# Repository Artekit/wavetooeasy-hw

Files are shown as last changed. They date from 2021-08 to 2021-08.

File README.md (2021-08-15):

# Artekit WaveTooEasy - Hardware files

This repository contains the Eagle files and mechanical drawings for the [Artekit WaveTooEasy](https://www.artekit.eu/products/devboards/wavetooeasy/) board.

(https://www.artekit.eu/products/devboards/wavetooeasy/)

## Links

* [WaveTooEasy product page](https://www.artekit.eu/products/devboards/wavetooeasy/)
* [WaveTooEasy manual](https://www.artekit.eu/doc/guides/wavetooeasy/)
* [WaveTooEasy - Library for Arduino](https://github.com/Artekit/Artekit_WaveTooEasy)
* [WaveTooEasy - Generic C library](https://github.com/Artekit/wavetooeasy-c-lib)

## Bugs report

You can report bugs here by creating a new issue or in the [Artekit forum](https://forum.artekit.eu/).

## License

Attribution-ShareAlike 3.0 Unported (CC BY-SA 3.0)

Copyright (c) 2021 Artekit Labs.

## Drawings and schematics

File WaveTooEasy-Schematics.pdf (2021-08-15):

# MCU ARM CORTEX M4 MECHANICAL

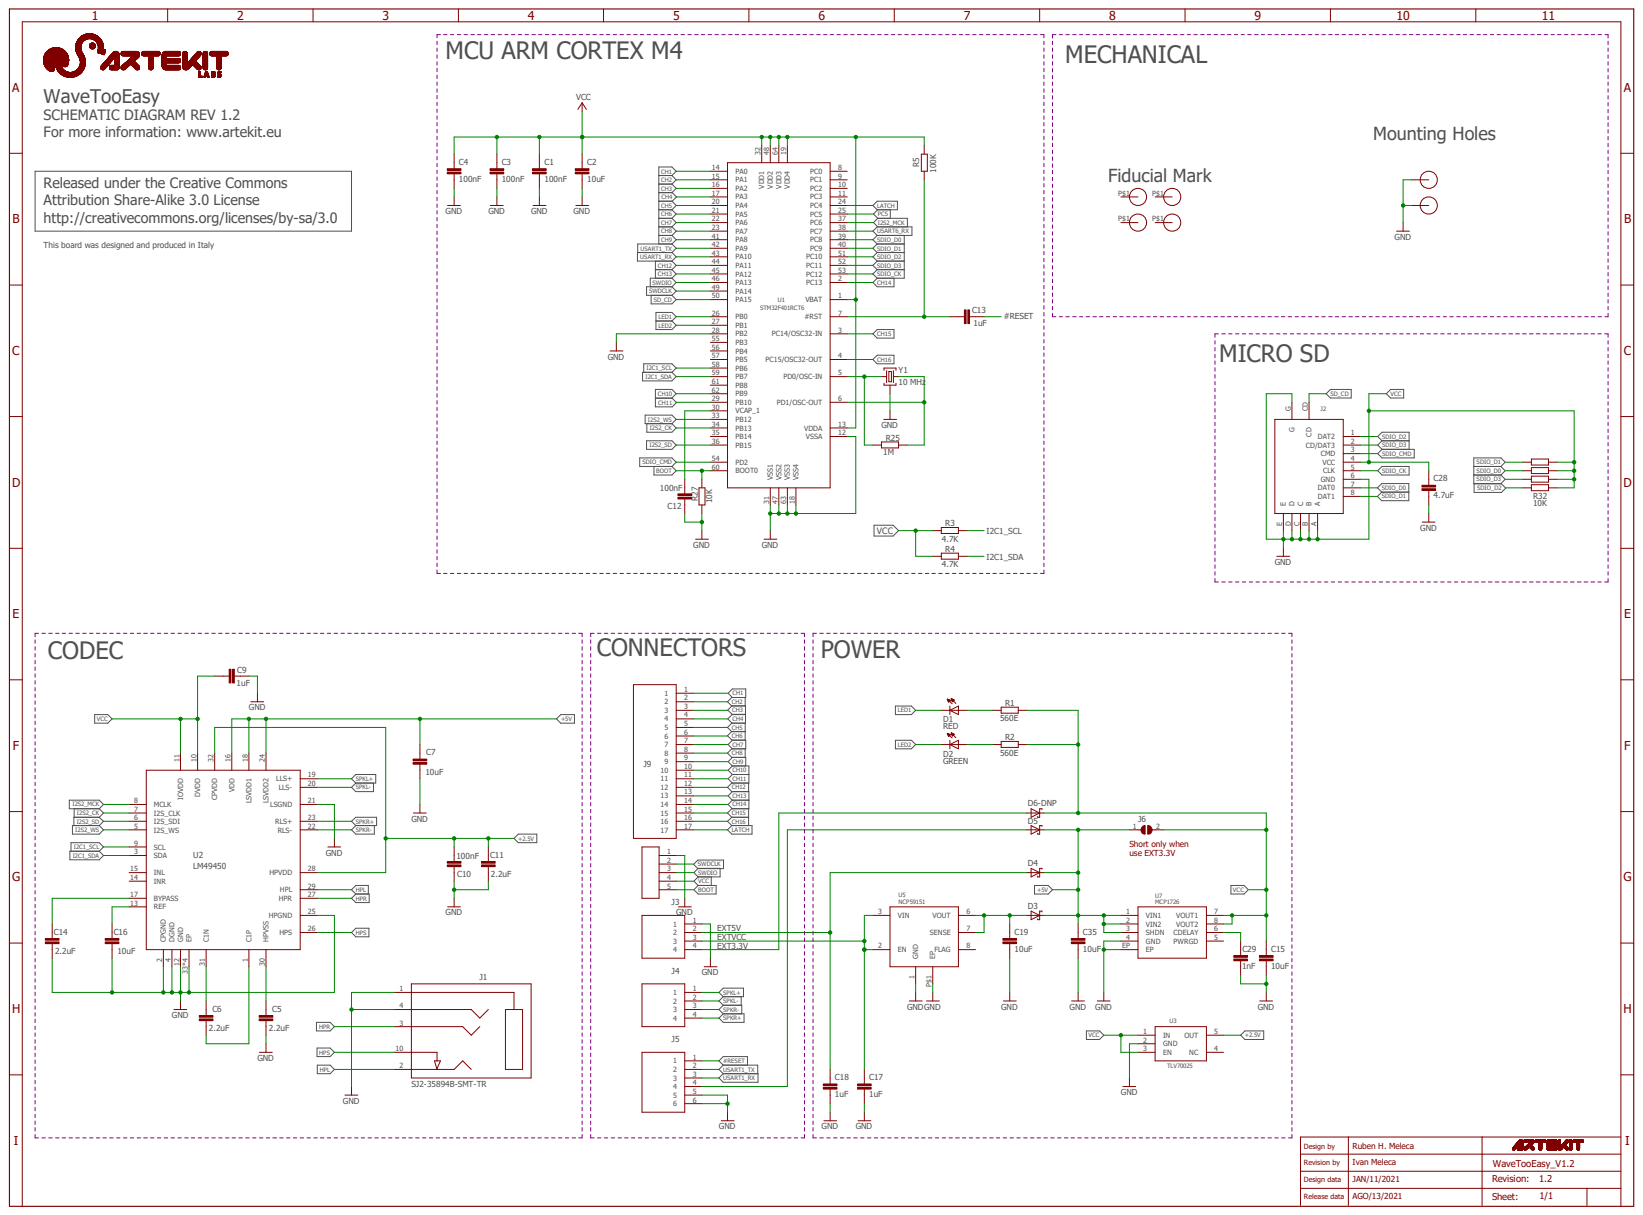
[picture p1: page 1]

WaveTooEasy
SCHEMATIC DIAGRAM REV 1.2
For more information: www.artekit.eu

Released under the Creative Commons
Attribution Share-Alike 3.0 License
http://creativecommons.org/licenses/by-sa/3.0

3 | EXTVCC

Design by | Ruben H. Meleca
Revision by | Ivan Meleca | WaveTooEasy_V1.2

Design data | JAN/11/2021 | Revision: 1.2
Release data | AGO/13/2021 | Sheet: 1/1

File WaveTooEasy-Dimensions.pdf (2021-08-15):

1.90 4.50 14.16

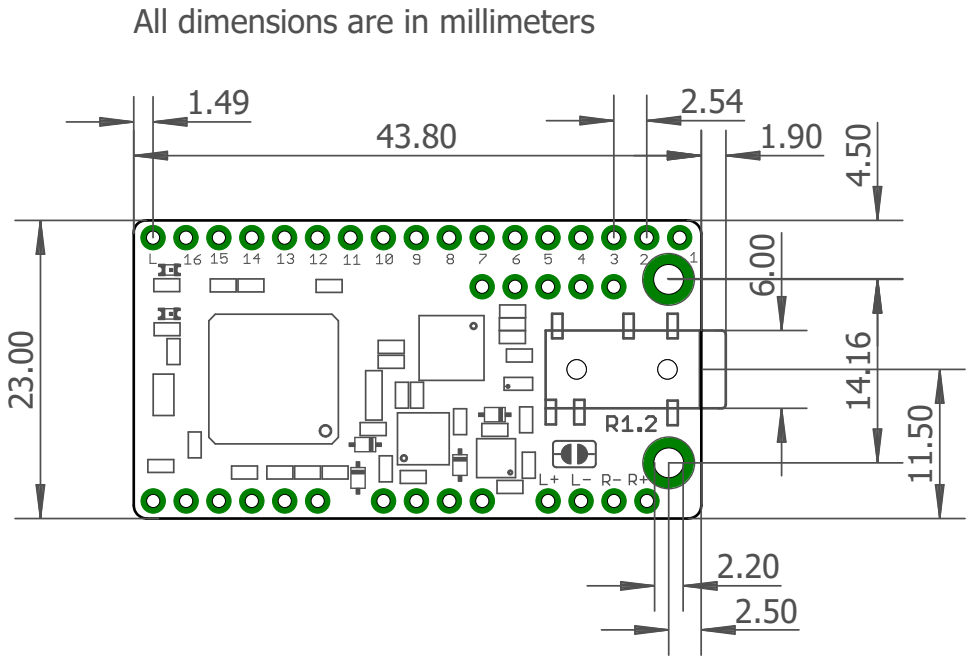
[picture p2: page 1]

All dimensions are in millimeters

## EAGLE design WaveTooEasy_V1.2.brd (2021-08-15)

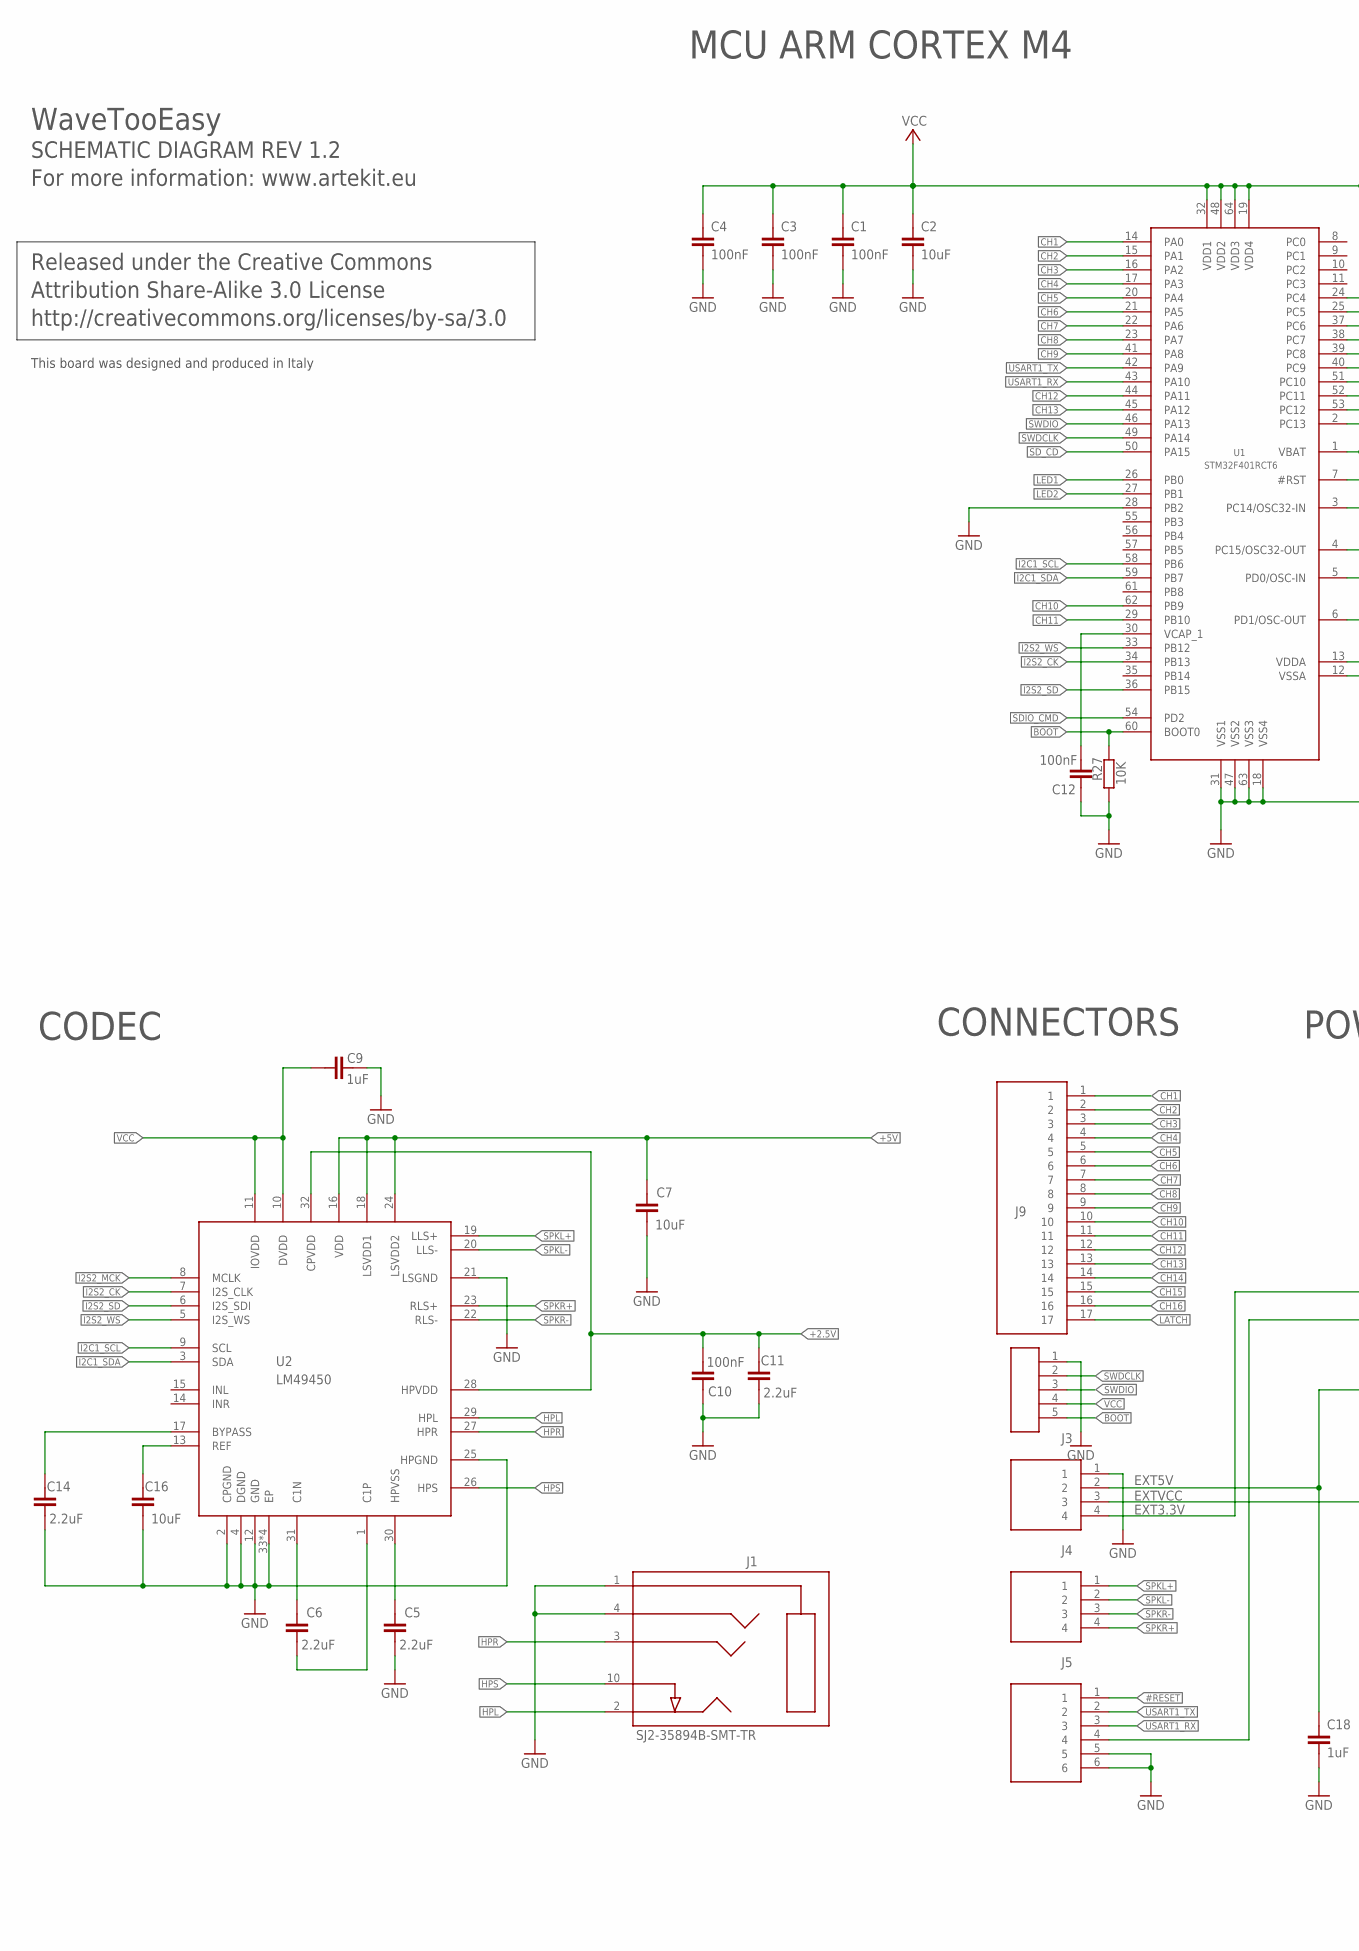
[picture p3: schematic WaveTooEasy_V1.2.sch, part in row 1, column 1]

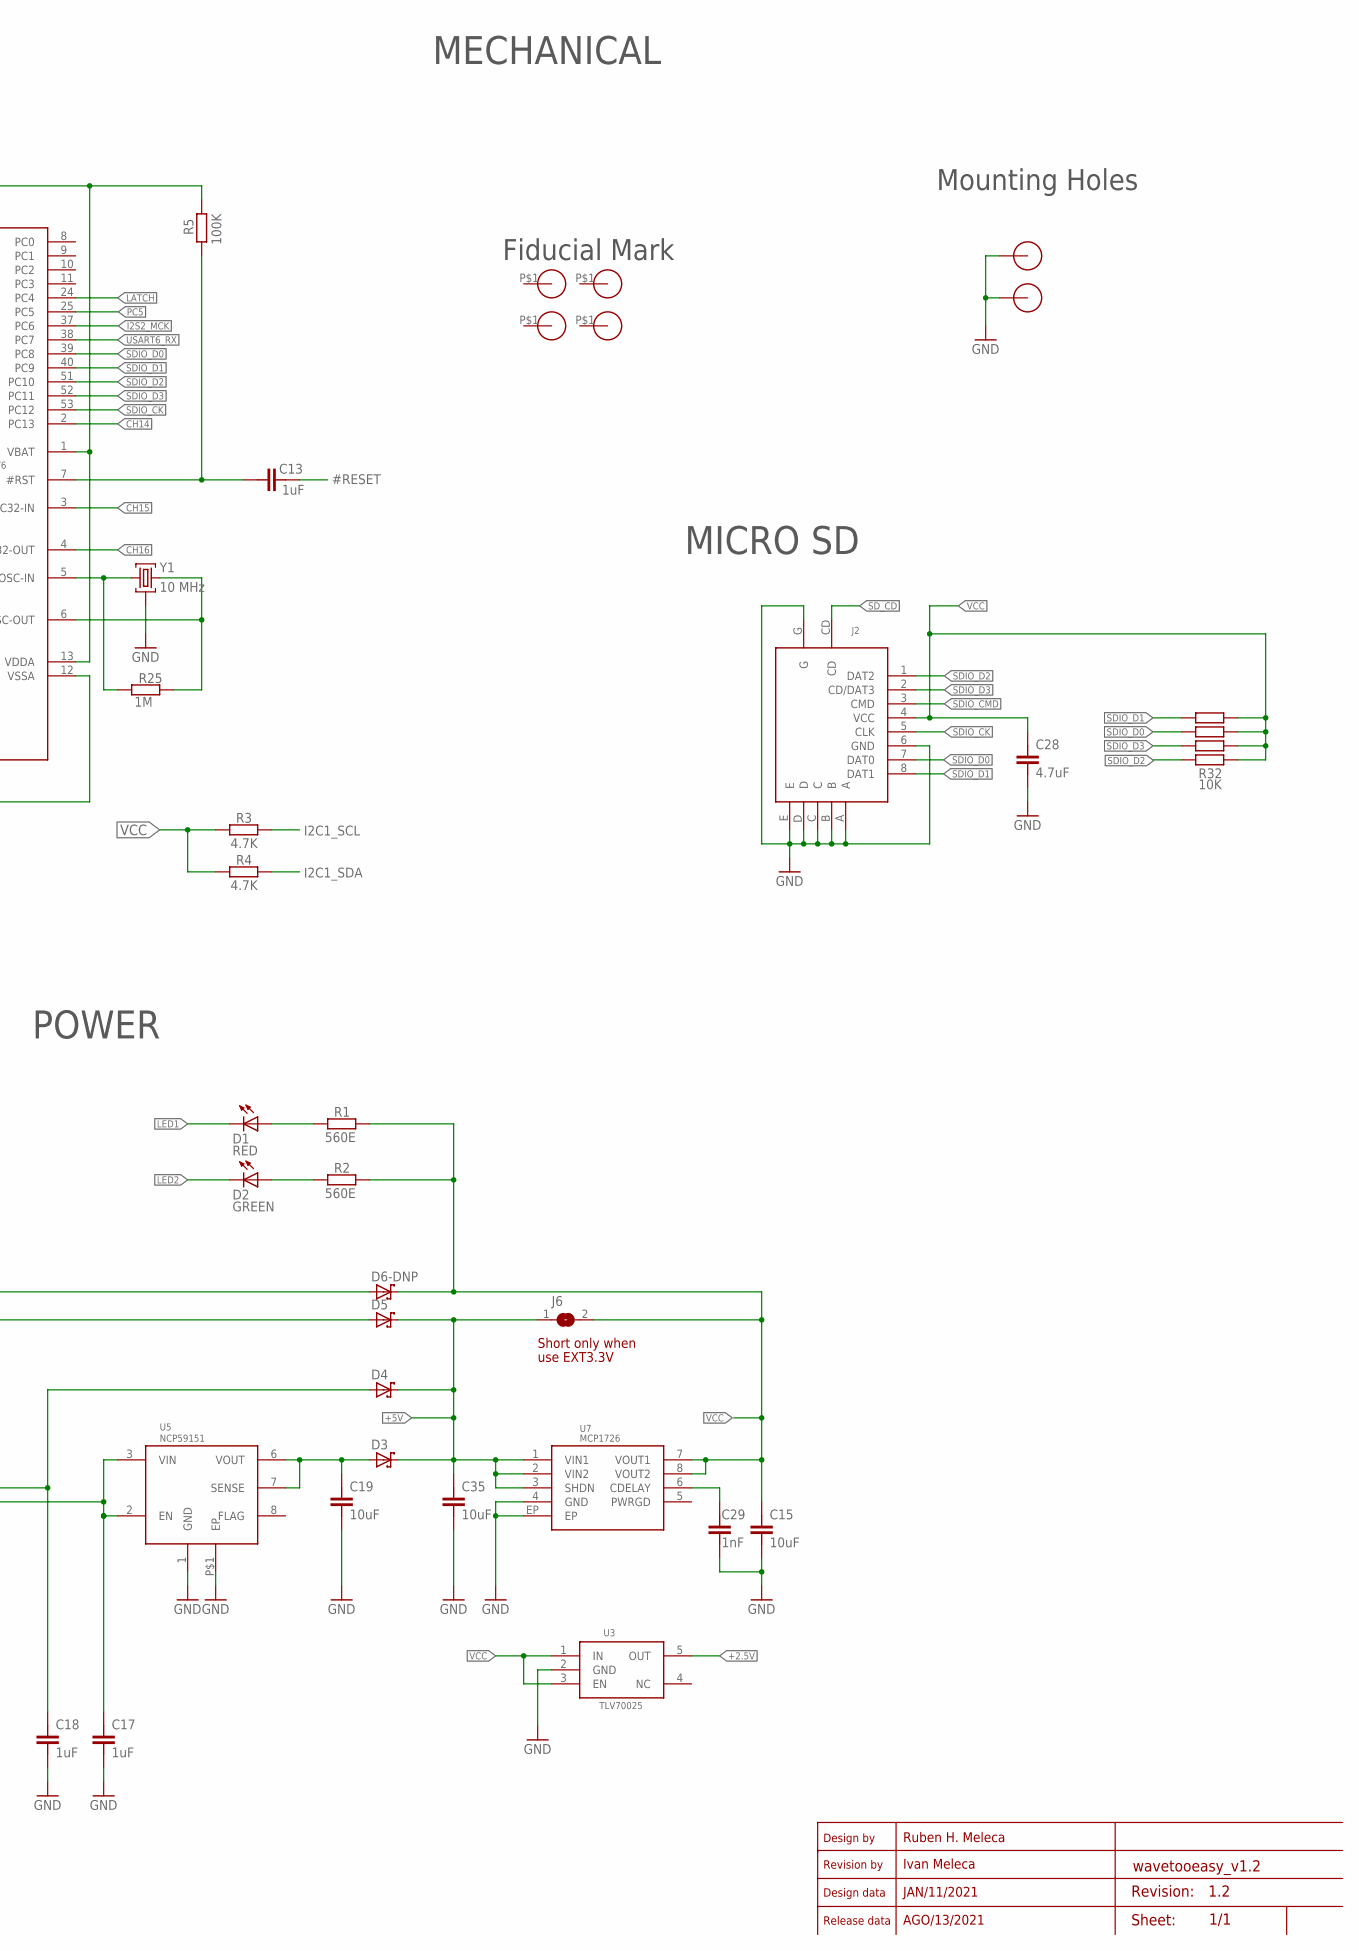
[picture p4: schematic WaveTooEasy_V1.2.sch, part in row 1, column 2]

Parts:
C1, C3, C4, C10, C12: 100nF; C0402
C2, C7, C15, C16, C19, C35: 10uF; C0402
C5, C6, C11, C14: 2.2uF; C0402
C9, C13, C17, C18: 1uF; C0402
C28: 4.7uF; C0402
C29: 1nF; C0402
D1: RED; CHIPLED_0603
D2: GREEN; CHIPLED_0603
D3, D4, D5, D6-DNP: BAT60; SOD-323
J1: SJ2-35894B-SMT-TR
J2: MICRO-SD-CON-MOLEX-503182-0852
J3, J4: CON-PH-1X04-P01"2; PIN-HEADER-1X04-NODASH
J5: CON-PH-1X06-P0.1"1; PIN-HEADER-1X6-NODASH
J6: JUMPER-2
J9: CON-PH-1X17-P0.1; PIN-HEADER-1X17-NODASH
R1, R2: 560E; R0402
R3, R4: 4.7K; R0402
R5: 100K; R0402
R25: 1M; R0402
R27: 10K; R0402
R32: 10K; RES-ARRAY-0603
U1: STM32F401RCT6; LQFP64-10X10-P0.50; MPN STM32F401RCT6
U2: LM49450; QFN32-5X5-P0.50
U3: TLV70025; SOT363-5
U5: NCP59151; DFN8-4X4
U7: MCP1726; DFN8-3X3
U$1: CON-PH-1X05-P0.1"; PIN-HEADER-1X05-NODASH
U$3, U$4: HOLE-2MM-METALIZED
U$5, U$6, U$8, U$9: FIDUTIAL_1.2MM
Y1: 10 MHz; RESONATOR-MURATA-CSTCE-SERIES

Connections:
#RESET: C13.2, J5.1
+2.5V: C10.1, C11.1, U2.28 (HPVDD), U2.32 (CPVDD), U3.5 (OUT)
+5V: C7.1, C35.1, D3.C, D4.C, D5.C, J6.1, U2.16 (VDD), U2.18 (LSVDD1), U2.24 (LSVDD2), U7.1 (VIN1), U7.2 (VIN2), U7.3 (SHDN)
BOOT: R27.2, U1.60 (BOOT0), U$1.5
CH1: J9.1, U1.14 (PA0)
CH2: J9.2, U1.15 (PA1)
CH3: J9.3, U1.16 (PA2)
CH4: J9.4, U1.17 (PA3)
CH5: J9.5, U1.20 (PA4)
CH6: J9.6, U1.21 (PA5)
CH7: J9.7, U1.22 (PA6)
CH8: J9.8, U1.23 (PA7)
CH9: J9.9, U1.41 (PA8)
CH10: J9.10, U1.62 (PB9)
CH11: J9.11, U1.29 (PB10)
CH12: J9.12, U1.44 (PA11)
CH13: J9.13, U1.45 (PA12)
CH14: J9.14, U1.2 (PC13)
CH15: J9.15, U1.3 (PC14/OSC32-IN)
CH16: J9.16, U1.4 (PC15/OSC32-OUT)
EXT3.3V: D6-DNP.A, J3.4
EXT5V: C18.1, D4.A, J3.2
EXTVCC: C17.1, J3.3, U5.2 (EN), U5.3 (VIN)
GND: C1.2, C2.2, C3.2, C4.2, C5.2, C7.2, C9.2, C10.2, C11.2, C12.2, C14.2, C15.2, C16.2, C17.2, C18.2, C19.2, C28.2, C29.2, C35.2, J1.1, J1.4, J2.6 (GND), J2.A, J2.B, J2.C, J2.D, J2.E, J2.G, J3.1, J5.5, J5.6, R27.1, U1.12 (VSSA), U1.18 (VSS4), U1.28 (PB2), U1.31 (VSS1), U1.47 (VSS2), U1.63 (VSS3), U2.2 (CPGND), U2.4 (DGND), U2.12 (GND), U2.21 (LSGND), U2.25 (HPGND), U2.33 (EP), U2.34 (EP), U2.35 (EP), U2.36 (EP), U3.2 (GND), U5.1 (GND), U5.P$1 (EP), U7.4 (GND), U7.EP, U$1.1, U$3.1, U$4.1, Y1.2
HPL: J1.2, U2.29 (HPL)
HPR: J1.3, U2.27 (HPR)
HPS: J1.10, U2.26 (HPS)
I2C1_SCL: R3.1, U1.58 (PB6), U2.9 (SCL)
I2C1_SDA: R4.1, U1.59 (PB7), U2.3 (SDA)
I2S2_CK: U1.34 (PB13), U2.7 (I2S_CLK)
I2S2_MCK: U1.37 (PC6), U2.8 (MCLK)
I2S2_SD: U1.36 (PB15), U2.6 (I2S_SDI)
I2S2_WS: U1.33 (PB12), U2.5 (I2S_WS)
LATCH: J9.17, U1.24 (PC4)
LED1: D1.C, U1.26 (PB0)
LED2: D2.C, U1.27 (PB1)
unnamed: C19.1, D3.A, U5.6 (VOUT), U5.7 (SENSE)
unnamed: C6.1, U2.31 (C1N)
unnamed: C6.2, U2.1 (C1P)
unnamed: C5.1, U2.30 (HPVSS)
unnamed: C16.1, U2.13 (REF)
unnamed: C14.1, U2.17 (BYPASS)
unnamed: D5.A, J5.4
unnamed: C13.1, R5.1, U1.7 (#RST)
unnamed: R25.1, U1.5 (PD0/OSC-IN), Y1.1
unnamed: R25.2, U1.6 (PD1/OSC-OUT), Y1.3
unnamed: D2.A, R2.2
unnamed: D1.A, R1.2
unnamed: C29.1, U7.6 (CDELAY)
unnamed: C12.1, U1.30 (VCAP_1)
PC5: U1.25 (PC5)
SDIO_CK: J2.5 (CLK), U1.53 (PC12)
SDIO_CMD: J2.3 (CMD), U1.54 (PD2)
SDIO_D0: J2.7 (DAT0), R32.3, U1.39 (PC8)
SDIO_D1: J2.8 (DAT1), R32.1, U1.40 (PC9)
SDIO_D2: J2.1 (DAT2), R32.7, U1.51 (PC10)
SDIO_D3: J2.2 (CD/DAT3), R32.5, U1.52 (PC11)
SD_CD: J2.CD, U1.50 (PA15)
SPKL+: J4.1, U2.19 (LLS+)
SPKL-: J4.2, U2.20 (LLS-)
SPKR+: J4.4, U2.23 (RLS+)
SPKR-: J4.3, U2.22 (RLS-)
SWDCLK: U1.49 (PA14), U$1.2
SWDIO: U1.46 (PA13), U$1.3
USART1_RX: J5.3, U1.43 (PA10)
USART1_TX: J5.2, U1.42 (PA9)
USART6_RX: U1.38 (PC7)
VCC: C1.1, C2.1, C3.1, C4.1, C9.1, C15.1, C28.1, D6-DNP.C, J2.4 (VCC), J6.2, R1.1, R2.1, R3.2, R4.2, R5.2, R32.2, R32.4, R32.6, R32.8, U1.1 (VBAT), U1.13 (VDDA), U1.19 (VDD4), U1.32 (VDD1), U1.48 (VDD2), U1.64 (VDD3), U2.10 (DVDD), U2.11 (IOVDD), U3.1 (IN), U3.3 (EN), U7.7 (VOUT1), U7.8 (VOUT2), U$1.4

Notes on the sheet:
POWER
CONNECTORS
MCU ARM CORTEX M4
MICRO SD
MECHANICAL
Released under the Creative Commons
Attribution Share-Alike 3.0 License
http://creativecommons.org/licenses/by-sa/3.0
This board was designed and produced in Italy
Fiducial Mark
Mounting Holes
CODEC
Sheet:
Design by
Revision by
Design data
Release data
Revision:
Ruben H. Meleca
Ivan Meleca
JAN/11/2021
AGO/13/2021
1.2
Short only when
use EXT3.3V
WaveTooEasy
SCHEMATIC DIAGRAM REV 1.2
For more information: www.artekit.eu

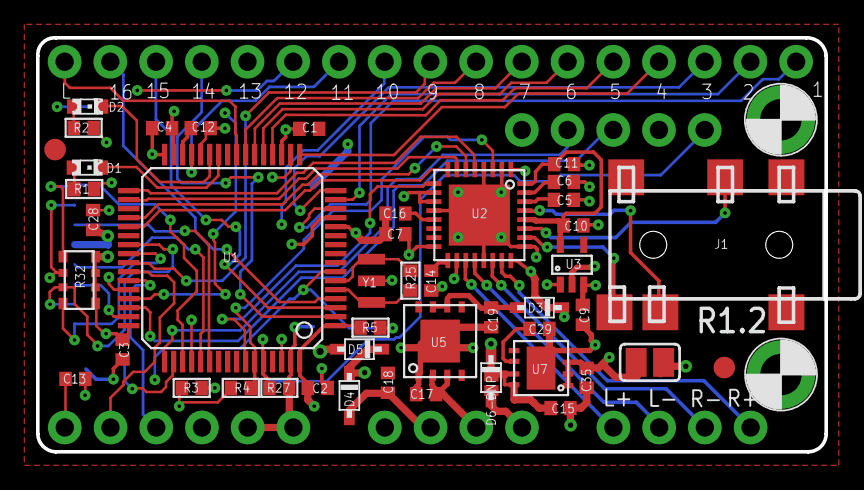
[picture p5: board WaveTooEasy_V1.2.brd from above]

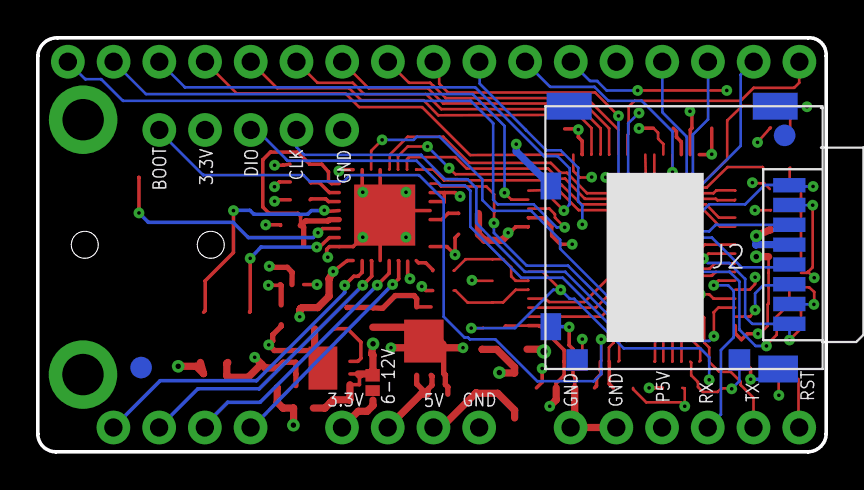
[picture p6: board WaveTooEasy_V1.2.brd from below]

Board: 2 copper layers, 43.8 x 23.0 mm, 55 parts (3 on the bottom side), 66 nets.
